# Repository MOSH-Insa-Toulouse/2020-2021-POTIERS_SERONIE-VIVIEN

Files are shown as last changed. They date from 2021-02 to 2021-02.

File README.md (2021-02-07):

# 2020-2021-POTIERS_SERONIE-VIVIEN

This project is part of the 5ISS year formation at INSA Toulouse.
After designing a nanoparticle gas sensor in the AIME laboratory at INSA Toulouse, we worked on the modeling of the assembly that would allow us to publish its measurements on the campus LoRa gateway.

Tool used : http://kicad-pcb.org/

# KiCad PCB 

The final structure is composed of :

- [x] The gas sensor
- [x] An amplifier stage for home-made gas sensor
- [x] A LoRa RN-2483 microchip for the data transmission
- [x] The Arduino Uno Shield that uses the same pin disposition as Uno board REV 3

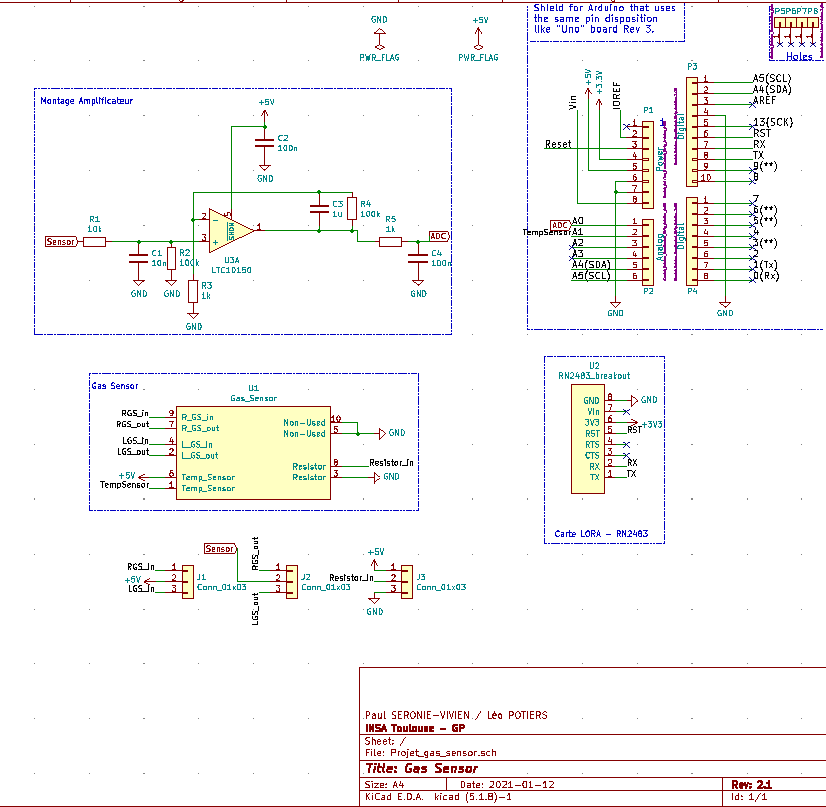
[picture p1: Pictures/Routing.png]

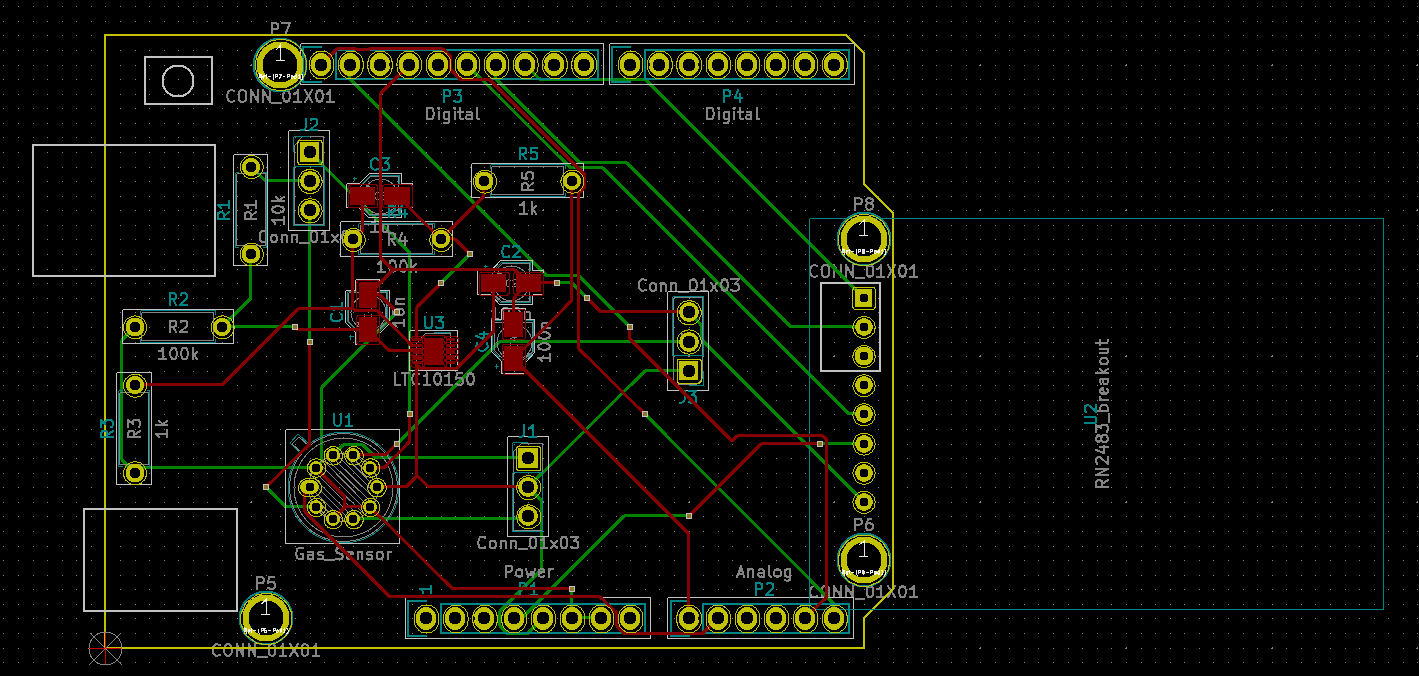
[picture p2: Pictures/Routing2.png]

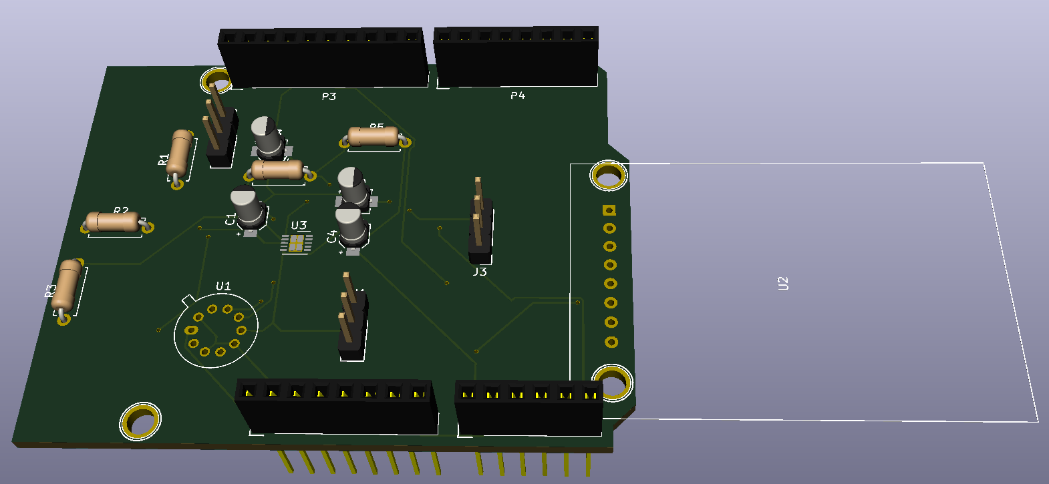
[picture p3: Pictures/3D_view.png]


# Datasheets of main components

- [x] Datasheet of the LoRa microchip
- [x] Datasheet of the home-made gas sensor
- [x] Datasheet of the Arduino UNO board

# To-Do List 

 - [x] Create KiCad project
 - [x] Design the circuit board
 - [x] Assign the components footprints
 - [x] Design of the pcb
 - [x] Component placement
 - [x] Routing

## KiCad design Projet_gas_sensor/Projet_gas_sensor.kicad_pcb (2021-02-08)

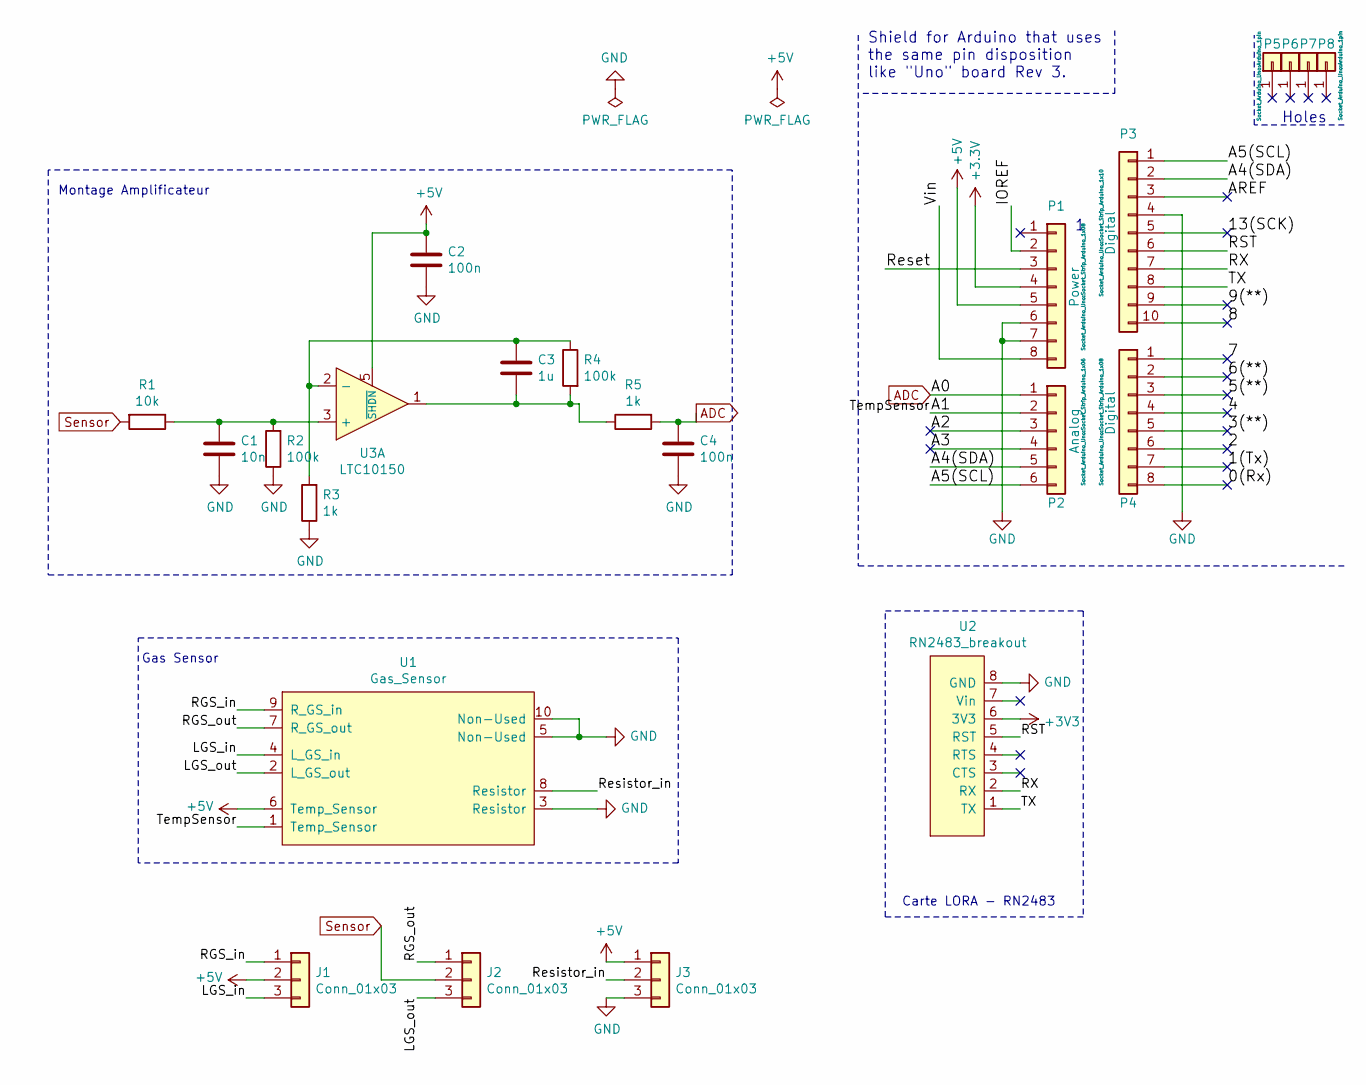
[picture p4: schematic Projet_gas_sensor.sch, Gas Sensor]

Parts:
C1: 10n; CP_Elec_3x5.3
C2, C4: 100n; CP_Elec_3x5.3
C3: 1u; CP_Elec_3x5.3
J1, J2, J3: Conn_01x03; PinHeader_1x03_P2.54mm_Vertical
P1: Power; Socket_Strip_Arduino_1x08
P2: Analog; Socket_Strip_Arduino_1x06
P3: Digital; Socket_Strip_Arduino_1x10
P4: Digital; Socket_Strip_Arduino_1x08
P5, P6, P7, P8: CONN_01X01; Arduino_1pin
R1: 10k; R_Axial_DIN0207_L6.3mm_D2.5mm_P7.62mm_Horizontal
R2, R4: 100k; R_Axial_DIN0207_L6.3mm_D2.5mm_P7.62mm_Horizontal
R3, R5: 1k; R_Axial_DIN0207_L6.3mm_D2.5mm_P7.62mm_Horizontal
U1: Gas_Sensor; TO-5-10_Window
U2: RN2483_breakout; LORA
U3: LTC10150; DFN-10-1EP_3x3mm_P0.5mm_EP1.65x2.38mm

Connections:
+5V: C2.1, J1.2, J3.1, P1.5, U1.6 (Temp_Sensor), U3.5 (~SHDN)
/0(Rx): P4.8
/1(Tx): P4.7
/2: P4.6
/3(**): P4.5
/4: P4.4
/5(**): P4.3
/6(**): P4.2
/7: P4.1
/8: P3.10
/9(**): P3.9
/13(SCK): P3.5
/A1: P2.2, U1.1 (Temp_Sensor)
/A2: P2.3
/A3: P2.4
/A4(SDA): P2.5, P3.2
/A5(SCL): P2.6, P3.1
/AREF: P3.3
/IOREF: P1.2
/LGS_in: J1.3, U1.4 (L_GS_in)
/LGS_out: J2.3, U1.2 (L_GS_out)
/RGS_in: J1.1, U1.9 (R_GS_in)
/RGS_out: J2.1, U1.7 (R_GS_out)
/RST: P3.6, U2.5 (RST)
/RX: P3.7, U2.2 (RX)
/Reset: P1.3
/Resistor_in: J3.2, U1.8 (Resistor)
/TX: P3.8, U2.1 (TX)
/Vin: P1.8
ADC: C4.1, P2.1, R5.2
GND: C1.2, C2.2, C4.2, J3.3, P1.6, P1.7, P3.4, R2.1, R3.1, U1.3 (Resistor), U1.5 (Non-Used), U1.10 (Non-Used), U2.8 (GND)
unnamed: C1.1, R1.1, R2.2, U3.3 (+)
unnamed: C3.1, R3.2, R4.1, U3.2 (-)
unnamed: C3.2, R4.2, R5.1, U3.1
Sensor: J2.2, R1.2

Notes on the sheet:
Holes
Shield for Arduino that uses the same pin disposition like "Uno" board Rev 3.
Carte LORA - RN2483
Gas Sensor
Montage Amplificateur

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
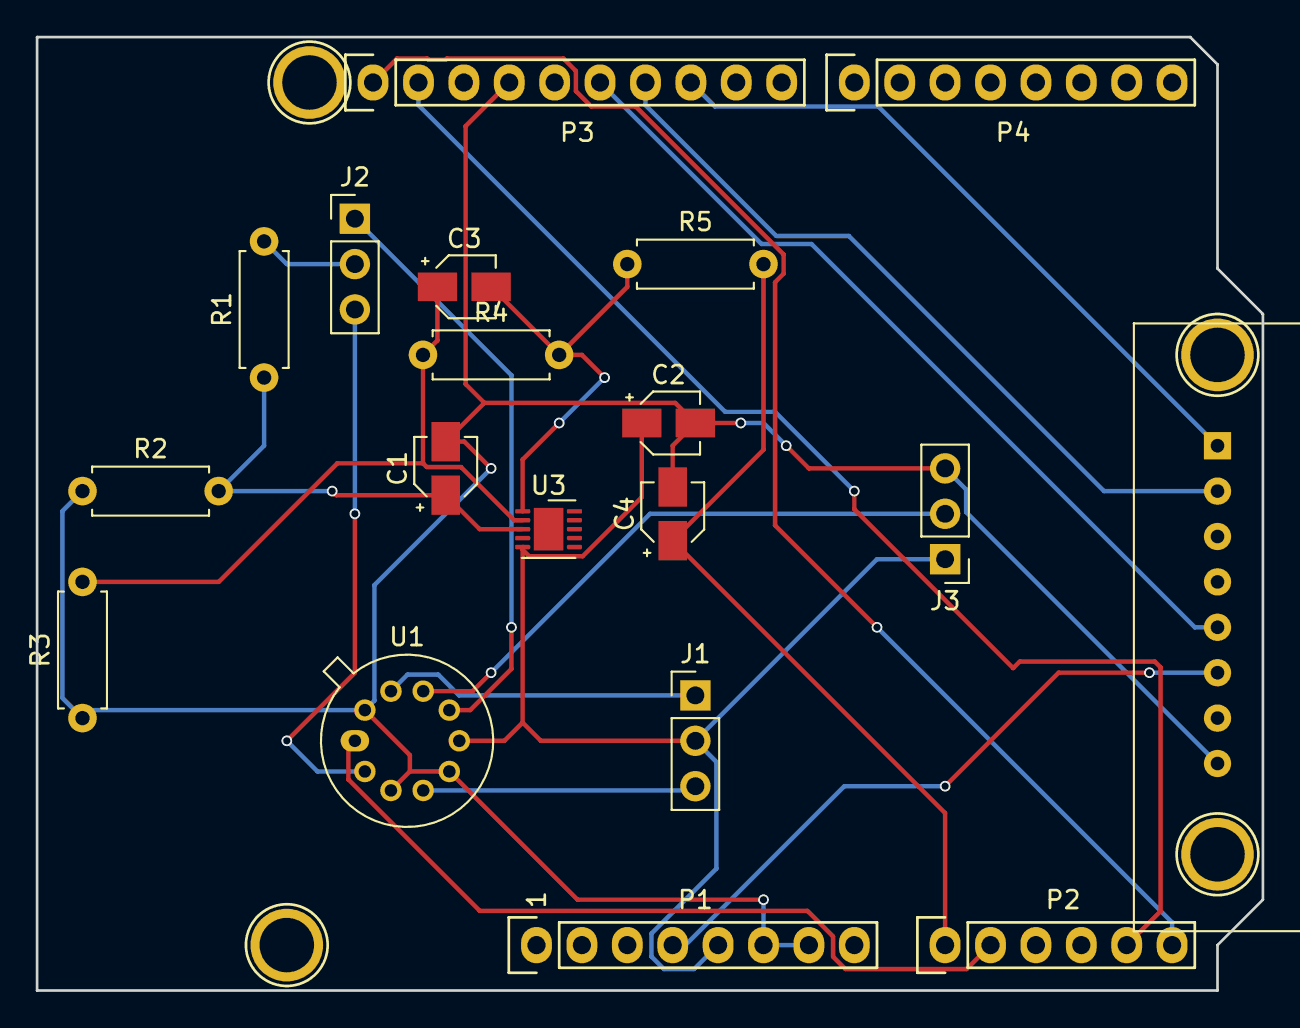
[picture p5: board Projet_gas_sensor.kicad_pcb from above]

Board: 2 copper layers, 68.6 x 53.3 mm, 23 parts (0 on the bottom side), 19 nets.
